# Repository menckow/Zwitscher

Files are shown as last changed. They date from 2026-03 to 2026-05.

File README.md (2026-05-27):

# Zwitscher - Directory-Based Random MP3 Player 🎵
Image of the Zwitscherbox
A smart, directory-based MP3 player based on the **ESP32-S3 (YB-ESP32-S3-AMP)** controller.

### ✨ Key features at a glance
- **Directory-based playback** with an intro sound for each folder.
- **PIR sensor** starts random MP3 playback when motion is detected — and, in v2, also fans out a family-circle signal so other boxes in the same circle light up.
- **Hardware controls** for volume (potentiometer) and folder selection (button).
- **Friendship lamp function (v2 family schema):** Lights up when *another* device in the same family circle sends a signal — whether that's a lamp button-press or another box's motion sensor. Lamp-originated signals are rendered with every 3rd LED in the complementary color so you can visually distinguish the source.
- **Family Circles:** Configure one or more `Familienkreise` (comma-separated) per box. The box belongs to all of them simultaneously and fans signals out to each.
- **Two separate MQTT integrations** for smart home systems (e.g. Home Assistant) and the friendship lamp function.
- **Configurable LED effects** (brightness, fade duration).
- **NVS memory** for volume and last folder to retain state after standby.
- **Integrated web portal** for easy configuration in the event of connection issues (including visual colour selection for the LED and family-circle assignment).
- **Web Upload OTA:** Drop a `.bin` directly via the configuration page — audio stops, LED turns blue, firmware is written in chunks and the box reboots automatically.
- **Central Device Management:** Fully compatible with the **Lamp Manager Dashboard**. Devices are grouped by family. Supports real-time status, version reporting, and Last Will (LWT) for offline detection.

## 🌟 Detailed features

- **Directory-based playback:** MP3s are organised into folders on the SD card. A button allows you to switch between directories.
- **Intro sound:** When switching folders, an `intro.mp3` file from the new directory is played automatically (if available).
- **Motion detector (PIR):** Detects movement and then plays a random MP3 file from the current directory. It also triggers the sending of an MQTT signal to the friendship lamp.
- **Hardware controls:**
  - **Potentiometer** for smooth and seamless volume control.
  - **Button** with debounce to switch directories.
- **Standby mode & NVS:**
  - After 5 minutes of inactivity, the ESP32 automatically enters **standby mode**. Audio playback stops and the LED ring is switched off, but Wi-Fi and MQTT remain active (important for the friendship lamp’s passive receiver function).
  - Wakes up internally when the PIR sensor is triggered or when a button is pressed.
  - The current directory and volume are stored in **NVS (Non-Volatile Storage)** to ensure data integrity.
- **Quiet Time (Do Not Disturb):**
  - Configurable via the Web UI, you can select your **Timezone** (e.g. Europe/Berlin) and define a sleep window (e.g. `22:00` to `08:00`). 
  - Using an internal background **NTP time sync**, the device will strictly ignore any incoming external colour MQTT signals during this window, ensuring it doesn't accidentally wake you up at night with bright LEDs. Local motion detection (PIR audio) continues to function.
- **Friendly lamp (RGB LED ring) — v2 family schema:**
  - **Presence:** If another device in the same family circle sends a signal — either a friend's lamp button-press or another box's PIR — your own LED ring lights up in the sender's color. Triggering *your own* PIR sensor does not cause your own lamp to light up, only fans the signal out to the family.
  - **Source-aware rendering:** Every signal carries a `sender_type` field. When the source is a **lamp**, every 3rd LED on the ring lights up in the complementary color — a clear visual hint that it came from a friend pressing a button. When the source is another **box** (PIR), the full ring lights up solid in the sender's color.
  - **Lamps ignore box signals** by design — a box's motion sensor doesn't wake a friend's lamp, only other boxes in the same family circle.
  - The LEDs fade in and out with a gentle **fade effect**. The duration and brightness can be adjusted in `config.txt`.
  - **Boot Check Sequence:** When powering on, the LEDs intuitively visualise the health of the boot process by lighting up individual LEDs sequentially in green (or red for failure) to signal initialisation stages (1. Hardware, 2. Wi-Fi, 3. Internal MQTT, 4. External MQTT).
- **Smart Home / MQTT Integration:**
  - The MQTT functionality is split into two parts:
    - An integration for **status messages** sent to an internal broker (e.g. Home Assistant).
    - A separate integration for the **Friendship Lamp feature**, which can also use a public broker.
    - Both can be enabled independently of one another. The device remains completely offline when both are disabled.
  - Connects via WiFi and sends real-time status updates via MQTT (volume, playback status, errors, current IP) **only** to the internal broker.
- **Timeouts:** The maximum playback duration for a random session is limited to 5 minutes to prevent endless playback.
- **Web configuration portal:** If a valid Wi-Fi connection cannot be established, the device launches its own password-protected access point (`Zwitscherbox`, **Password: `12345678`**). All settings can be conveniently configured via a web interface using drop-down menus (including a Wi-Fi scanner), without having to manually edit the SD card. The colour of the LED Ring (your colour) can be set particularly intuitively using a visual HTML colour picker. You can optionally secure this UI with a permanent administrator password.
- **SD Card File Manager:** The web interface also includes a fully-fledged `/files` file manager endpoint! This enables you to directly navigate the SD card directory, create new folders, delete files, and upload new MP3s over Wi-Fi without having to physically remove the SD card from the ESP32. Large MP3 files are smoothly transferred using asynchronous, memory-safe data chunks along with a live progress bar.
## 🛠 Hardware requirements

- **Board:** YB-ESP32-S3-AMP (based on Arduino ESP32 core >= v3.1.1)
- **SD card module:** Integrated (SPI)
- **PIR sensor:** Connected to `Pin 18`
- **Push button:** Connected to `Pin 17` (internal pull-up configured)
- **Potentiometer:** Connected to `Pin 4`
- **RGB LED ring (NeoPixel):** Data line connected to `Pin 16`
- **I2S Audio:** Pins for I2S configuration (integrated into the audio library).

## 🗂 Folder structure on the SD card
The SD card should be formatted as follows:
```
/
├── config.txt                   # (Optional) Wi-Fi and MQTT configuration
├── BirdSounds/                  # Directory 1
│   ├── intro.mp3                # Intro for Directory 1 (‘You are now listening to birds’)
│   ├── blackbird.mp3
│   └── thrush.mp3
└── Waterfall/                   # Directory 2
    ├── intro.mp3
    ├── waterfall1.mp3
    └── waterfall2.mp3
```

## ⚙️ Configuration (`config.txt`)

To use MQTT and Wi-Fi, create a `config.txt` file in the root directory of the SD card. Here is an example with all the new options:

```ini
# --- 1. MQTT activation ---
# Set this value to 1 to enable status reporting to your internal
# MQTT broker (e.g. Home Assistant).
MQTT_INTEGRATION=1

# Set this value to 1 to enable the Friend Lamp function via MQTT
#. This can be the internal broker or a public broker.
FRIENDLAMP_MQTT_INTEGRATION=1

# Note: If both of the above values are set to 0, the device remains offline (no Wi-Fi).

# --- 2. Wi-Fi settings ---
# Required if any of the MQTT integrations are enabled.
WIFI_SSID=YourWi-FiName
WIFI_PASS=YourWi-FiPassword

# --- 3. Internal MQTT broker (for Home Assistant) ---
MQTT_SERVER=192.168.1.100
MQTT_PORT=1883
MQTT_USER=mqtt_user
MQTT_PASS=mqtt_password
MQTT_CLIENT_ID=ESP32_AudioPlayer
MQTT_BASE_TOPIC=audioplayer

# --- 5. Friendship Lamp (RGB LED ring) ---
# Turns the LED ring hardware on (1) or off (0).
FRIENDLAMP_ENABLE=1
# Fixed transmission colour for THIS box in hexadecimal format (visually selectable in the web portal)
FRIENDLAMP_COLOR=0000FF
# v2 family schema: comma-separated list of family circle IDs the box belongs to.
# The box will subscribe to `fl/family/<id>/signal` for each entry and fan its
# PIR-triggered signals out to all of them. Whitespace is trimmed and entries
# are lowercased automatically.
FAMILY_IDS=schmidt,lieblings

# Control for LED effects
LED_FADE_EFFECT=1
LED_FADE_DURATION=1000
LED_BRIGHTNESS=100

# --- External broker for the friendship lamp (optional) ---
# If these fields are left blank, the internal broker is used automatically.
FRIENDLAMP_MQTT_SERVER=broker.hivemq.com
FRIENDLAMP_MQTT_PORT=1883
FRIENDLAMP_MQTT_USER=
FRIENDLAMP_MQTT_PASS=

# TLS encryption (only relevant for the external Friendlamp broker)
# Set to 1 to encrypt the connection to the Friendlamp broker (usually port 8883).
# The internal Home Assistant broker remains unaffected and unencrypted.
FRIENDLAMP_MQTT_TLS_ENABLED=0

# If TLS is enabled, the root certificate (BEGIN_CERT...END_CERT) must be included in config.txt.
```
If the file is omitted or both `_INTEGRATION` flags are set to `0`, the player runs completely offline.

## 🔘 Folder Taster & IP Address Visualization

The folder-change push button (connected to `Pin 17` or mapped Key on Audio Kit) has dual functions:
* **Short Press (< 3 seconds)**: Stops the current playback, changes to the next directory on the SD card, and plays the directory's intro sound.
* **Long Press (>= 3 seconds)**: Triggers the visual readout of the **last octet of the local IP address** on the RGB LED ring.
  * **Visual Pattern (Blinking Mode)**:
    * The last number of the IP address (e.g. `174` in `192.168.178.174`) is read out digit by digit.
    * For each digit $D$ (0 to 9), the entire LED ring flashes white $D + 1$ times (500 ms ON / 500 ms OFF).
    * To separate hundreds, tens, and ones, the entire LED ring lights up **Red for 1 second** (followed by a 500 ms pause).
  * **Note**: Releasing the button after the IP display starts will **not** trigger a folder change.

## 🚀 Installation & Compilation

This project uses **PlatformIO**. 
1. Clone or download the repository.
2. Open the folder in VSCode / PlatformIO.
3. The dependencies (such as `ESP32-audioI2S` and `PubSubClient`) are automatically downloaded via `platformio.ini` during the first build.
4. Connect the board via USB and click **Upload and Monitor**.

## 📡 MQTT Topics (v2 Family Schema)

When the MQTT connection is active, the box uses two topic families:

**Home Assistant / internal status** (based on `MQTT_BASE_TOPIC`, e.g. `audioplayer`):
* `audioplayer/status`: Status messages (‘Online’, ‘Playing Intro’, ‘Entering Standby’, ‘Woke up from Standby’, etc.)
* `audioplayer/volume`: Current volume.
* `audioplayer/directory`: The path to the newly selected directory on the SD card.
* `audioplayer/playing`: The path of the MP3 file currently being played or ‘STOPPED’.
* `audioplayer/ip_address`: The current IP address on the Wi-Fi network.
* `audioplayer/error`: Error messages (e.g. file system errors, missing MP3s).

**v2 family schema** (shared between lamps and boxes; consumed by the Dashboard):

| Purpose | Topic | Retained |
|---|---|---|
| Family signal (publisher + subscriber) | `fl/family/<familyId>/signal` | no |
| Device status (JSON) | `fl/device/<deviceId>/status` | **yes** |
| OTA per single device | `fl/device/<deviceId>/update/trigger` | no |
| OTA per family (boxes only) | `fl/family/<familyId>/update/trigger/box` | no |
| Global emergency OTA (boxes only) | `fl/_global/update/trigger/box` | no |
| OTA progress backchannel | `fl/device/<deviceId>/update/status` | no |

### 📝 Device Status Payload (retained JSON)

```json
{
  "type": "box",
  "fw": "V7.0.0",
  "state": "online",
  "color": "#0000FF",
  "families": ["schmidt", "lieblings"]
}
```

### 📝 Signal Payload (v2 family signal)

```json
{
  "client_id": "Kueche-Schmidt",
  "sender_type": "box",
  "color": "#0000FF",
  "effect": "fade",
  "duration": 30000,
  "ts": 1716729600
}
```

Fields explained:
- **`client_id`** (string): Unique device name (defined in `MQTT_CLIENT_ID`). Used for the **self-filter** so the box never reacts to its own messages.
- **`sender_type`** (string): Either `"lamp"` (button-press from a Friendship Lamp) or `"box"` (PIR-trigger from another box). Receivers use this to choose the LED rendering mode — lamps as source → complementary-color mode, boxes as source → solid color. Lamps additionally ignore any signal with `sender_type:"box"` so a box's motion sensor never wakes a friend's lamp.
- **`color`** (string): HEX color code (e.g. `#00FF00`). The literal `RAINBOW` triggers the rainbow effect.
- **`effect`** (string): `"fade"`, `"blink"`, or `"rainbow"`.
- **`duration`** (integer, ms): How long the LEDs stay lit before switching off (default `30000`).
- **`ts`** (Unix timestamp, optional): NTP-validated; signals older than 60 s are dropped to prevent retained messages from re-triggering after reconnect.

### 🔄 OTA Updates

Three update channels are supported, all using the same JSON payload format:

```json
{
  "url": "http://your-server.com/firmware.bin",
  "version": "7.0.1",
  "md5": "b3e3e3b3e3e3b3e3e3b3e3e3b3e3e3b3",
  "target_type": "box"
}
```

| Channel | Topic | Use case |
|---|---|---|
| Per-device | `fl/device/<deviceId>/update/trigger` | Update one specific box from the Dashboard |
| Per-family | `fl/family/<familyId>/update/trigger/box` | Update all boxes in a single family circle |
| Global | `fl/_global/update/trigger/box` | Emergency push across all boxes |

The `target_type` field is an optional defense-in-depth check — devices verify it matches their own type (`"box"`) before applying the update.

**Key Security & UI Features:**
- **Strict MD5 Validation:** The firmware verifies the provided `md5` hash internally before activating the new code. If the 32-character hash is missing or mismatched, the box aborts the update.
- **Dynamic LED Progress Ring:** During download, the RGB ring is repainted blue with progressive coverage.
- **Live MQTT Status Broadcasting:** The box streams download percentage updates (`Updating (30%)`, etc.) back to `fl/device/<deviceId>/update/status` and updates its main status topic as JSON.
- **Audio is automatically stopped** when an OTA starts, to keep the I²S DMA and Flash writes from colliding.
- If the installation fails the NeoPixel ring flashes red and the previous firmware continues to run.

### 💾 Web Upload OTA

In addition to the MQTT-triggered channels, the configuration page exposes a **Firmware-Update** section. Pick a `.bin`, optionally paste an MD5 hash, and submit. The box validates, writes via chunked `Update.write()`, and reboots automatically. Useful for first-time provisioning or when MQTT is temporarily unavailable.

## 📄 Licence

This project was developed exclusively as a private/open-source solution. 

## 🐞 Troubleshooting

### Build error: ‘not able to power down in light sleep’

When compiling the project, the following error message may appear, which typically occurs during the initialisation of the NeoPixel LED ring:

```
E (3637) rmt: rmt_new_tx_channel(269): unable to power down into light sleep
[  3664][E][esp32-hal-rmt.c:548] rmtInit(): GPIO 16 - RMT TX initialisation error.
```

- **Cause:** This error is caused by a bug in older versions of the ESP32 framework (Arduino Core) for PlatformIO. The RMT peripheral driver used by the NeoPixel library has a compatibility issue with the ESP32’s power-saving modes.

- **Solution:** To resolve this, the `platformio.ini` file has been modified. The `platform` setting has been set to a specific Git repository containing a newer version of the framework that fixes this error whilst also providing the necessary board definitions for the YB-ESP32-S3-AMP board.

The relevant line in `platformio.ini` is:
```ini
[env]
platform = https://github.com/pioarduino/platform-espressif32.git
```

This change ensures that the project is built using a compatible and bug-fixed version of the ESP32 framework.

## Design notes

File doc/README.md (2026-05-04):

# 🐦 Zwitscherbox & Friendship Lamp

A smart, motion-controlled MP3 player with an integrated light ring, Wi-Fi configuration portal, and smart home connectivity (MQTT).

## 🌟 Overview

This device combines an interactive MP3 player with a "Friendship Lamp". As soon as the motion detector (PIR) senses a person, the device plays a random audio file from the SD card.
Simultaneously, it can send a signal over the internet (MQTT) to a second box, causing its integrated LED ring to light up – so you instantly know when someone is thinking of you!

## ✨ Key Features

- **Motion Detection:** Automatically starts random audio playback upon detecting movement.
- **Directory System:** Supports multiple folders with different sounds. A button press changes the directory (confirmed by a short identification sound `intro.mp3`).
- **Friendship Lamp (LED Ring):**
  - **Standard Signal:** The entire ring illuminates (with a smooth fade if activated) and dims out again after 30 seconds.
  - **Friendship Signal:** The ring lights up, but every 3rd LED appears as a highlight in the *complementary color* for visual distinction.
- **Easy Setup:** No programming required – Wi-Fi, light color, and Smart Home server can be easily configured via a convenient web interface on your phone.
- **Smart-Home Ready:** Can be fully integrated into a Smart Home (e.g., Home Assistant) via MQTT (Status, Volume, Currently Playing Track, IP Address).
- **Auto Standby/Memory:** The device automatically remembers the current folder and volume. After 5 minutes of inactivity, the device independently enters power-saving mode.

---

## 🛠️ 1. Initial Setup (Wi-Fi Portal)

When the box is started for the first time (or cannot find its saved Wi-Fi), it automatically opens its own setup network.

1. Search for the Wi-Fi network **"Zwitscherbox"** with your smartphone or laptop and connect.
2. A login window (Captive Portal) should open automatically. Alternatively, open your browser and enter any address.
3. On the configuration page, you can configure all settings:
   - **Network Name & Password:** Enter your standard home Wi-Fi here.
   - **Select Color:** Determine which color your LED ring should light up in when the box receives a signal.
   - **MQTT / Smart Home:** (Optional) Enable the connection to your own or an external Smart Home server to connect the box with your friends.
4. Click on **"Save Configuration"**. The box will now restart and connect to the normal home Wi-Fi.

---

## 🎛️ 2. Operation on the Device

* **Volume Knob (Potentiometer):** Turn the knob to continuously adjust the volume.
* **Press Button:** Switches to the next audio folder on the SD card. A short identification melody is played during the switch, after which the system is immediately ready to react to motion again.
* **Motion Sensor:** If movement is detected, the device randomly selects an MP3 file from the current folder and plays it.

---

## 📁 3. SD Card Preparation

For the box to play music, the included SD card must be prepared as follows:

1. Create one or more subfolders on the SD card (e.g., `Birdsongs`, `ForestSounds`, `Music`).
2. Copy your desired sound files into each folder (they must end exactly with `.mp3`).
3. **IMPORTANT:** Add another MP3 file to every main folder and name it exactly `intro.mp3`. This will always be played briefly when someone switches to the folder using the button. This way, you immediately know which folder is currently activated.

---

## 💡 4. How Does the Illumination Work?

As soon as your box detects motion, it not only plays an audio file but also secretly broadcasts a signal in the background over the internet (MQTT) indicating which color you want to light up in.

* **Your box receives a generic "Zwitscherbox Signal":** The LED ring fills completely with the receiver color and smoothly transitions into a fade-out (dimming) after about 30 seconds. (Ideal for the main system).
* **Your box receives a signal on the "Friendship Channel":** A special pattern is visually displayed: The ring lights up, but every third LED shines as a highlight in the *complementary color*. This way, you can see at a glance on which of the two channels the box was currently addressed!

---

## 🔧 Technical Specifications (For the tech-savvy)
- **Components:** ESP32 (Model: YB-ESP32-S3-AMP), PIR Motion Sensor (Pin 18), Button (Pin 17), Analog Potentiometer (Pin 4), NeoPixel LED Ring (16 LEDs on Pin 16).
- **Storage:** NVS (Non-Volatile Storage) securely saves volume and folder selection across reboots.
- **Playback Safety:** Individual audio tracks have a built-in time limit of 5 minutes. If the room remains unused, the system silently enters standby mode.

---

## 📚 Additional Documentation

- [**PIR Ruhezeit & Sensor-Steuerung**](PIR_Ruhezeit_Dokumentation.md): Detailed information on PIR sensor behavior during Quiet Time and recent fixes.
- [**Architecture Refactoring**](Architecture_Refactoring.md): Overview of the V6 code structure and module separation.
- [**Wiring Diagram**](wiring_diagram.md): Connection guide for all hardware components.
- [**Visual Guide**](Zwitscherbox_Visual_Guide.md): Aesthetics and design overview.

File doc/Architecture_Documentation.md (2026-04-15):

# Zwitscherbox Software Architecture

Dieses Dokument beschreibt die objektorientierte (OOP) Architektur der Zwitscherbox (Friendship Lamp) Software. Die Code-Basis wurde entwickelt, um asynchrone Hardware-Ein-/Ausgaben, Webdienste, Dual-MQTT-Kommunikation und MP3-Wiedergabe stabil miteinander zu orchestrieren.

---

## 1. Klassendiagramm & Abhängigkeiten

Das Projekt nutzt das Prinzip der **Dependency Injection**. Das bedeutet, die `main.cpp` agiert lediglich als "Dirigent" (Orchestrator). Sie erstellt die Instanzen der einzelnen Manager-Klassen und ruft kontinuierlich deren `update()` Methoden in der `loop()` Schleife auf.

```mermaid
classDiagram
    class main {
        <<Orchestrator>>
        +setup()
        +loop()
    }
    
    class AppConfig {
        +load()
        +saveFromWeb()
        ~wifi_ssid
        ~friendlamp_enabled
    }

    class WebManager {
        -AsyncWebServer server
        -DNSServer dns
        +WebManager(port)
        +processDns()
        -setupWebServer()
        -startConfigPortal()
    }

    class MqttHandler {
        -PubSubClient mqttClient
        -PubSubClient mqttClientLamp
        +update()
        +publish()
        +publishLamp()
        -internalMqttReconnect()
    }

    class AudioEngine {
        -Audio audio
        -PlaybackState currentState
        -Preferences preferences
        +init()
        +update()
        -checkPirAndTimeout()
        -checkButton()
        -checkVolumePot()
    }

    class LedController {
        -Adafruit_NeoPixel strip
        -SemaphoreHandle_t mutex
        -ILedEffect* currentEffect
        +begin()
        +update()
        +setEffect(ILedEffect*)
    }

    class ILedEffect {
        <<Interface>>
        +update(strip) bool
    }

    %% Relationships
    main *-- AppConfig : instantiates globally
    main *-- WebManager : tick
    main *-- MqttHandler : tick
    main *-- AudioEngine : tick
    main *-- LedController : tick
    
    WebManager --> AppConfig : modifies
    MqttHandler --> AppConfig : reads
    AudioEngine --> AppConfig : reads
    
    AudioEngine --> MqttHandler : publishes status
    AudioEngine --> LedController : controls standby
    MqttHandler --> LedController : triggers colors
    LedController *-- ILedEffect : Strategy Pattern
    ILedEffect <|-- FadeEffect
    ILedEffect <|-- RainbowEffect
    ILedEffect <|-- BlinkEffect
```

---

## 2. Erklärung der Architektur (Klassen)

### 2.1 `AppConfig` (Datenhaltung)
Dies ist das Gehirn für Einstellungen. Es existiert global (`extern AppConfig config;`). 
- **Aufgabe**: Liest beim Start die Datei `/config.txt` von der SD-Karte ein und parst diese.
- Sämtliche anderen Klassen (`MqttHandler`, `WebManager`, etc.) greifen auf diese Instanz zu, um zu prüfen, ob z.B. `config.friendlamp_enabled` aktiv ist.

### 2.2 `WebManager` (Konfigurations-Portal)
Kapselt den Asynchronen Webserver (`AsyncWebServer`) und das Captive Portal (`DNSServer`).
- **Aufgabe**: Wenn keine WLAN-Verbindung möglich ist (oder über den Setup-Taster erzwungen), öffnet er ein eigens WLAN "Zwitscherbox".
- Bietet HTML-Seiten zur einfachen WLAN-, MQTT- und Farb-Konfiguration an.
- Nutzt asynchrone "Lambda-Funktionen", weshalb blockierender Code im `loop()` nicht mehr nötig ist.

### 2.3 `MqttHandler` (Netzwerk & Kommunikation)
Verwaltet simultan **zwei** MQTT-Broker:
1. Lokaler Home Assistant Broker (Steuerung / Status)
2. Externer/Öffentlicher Friendship Lamp Broker (Kommunikation mit anderen Lampen)
- **Aufgabe**: Sorgt asynchron dafür (`mqttHandler.update()`), dass die Verbindung gehalten wird. 
- Bei Empfang einer bestimmten Lampen-Nachricht übersetzt er diese in ein visuelles Signal und leitet es direkt an den `LedController` weiter.

### 2.4 `LedController` (Visuelle Effekte)
Abstraktionsschicht für den NeoPixel LED-Ring, die extrem weiche, blockierungsfreie Fades und Regenbögen ermöglicht.
- **Strategie-Muster (Strategy Pattern)**: Nutzt Effekte, die von der Basis `ILedEffect` erben. Der Controller ruft nur stumm `update()` auf. Ist der Effekt zu Ende (z.B. Fade Out), zerstört der LEDController das Effekt-Objekt automatisch aus dem Arbeitsspeicher.
- **Thread-Safety (FreeRTOS)**: Damit die asynchrone Audio-Bibliothek (`ESP32-audioI2S`) und der Webserver nicht gleichzeitig in den Speicher LEDs schreiben, wird ein "Mutex" (Semaphore) verwendet. Das verhindert Systemabstürze.

### 2.5 `AudioEngine` (State Machine & Hardware)
Die technisch komplexeste Klasse. Sie abstrahiert alle physischen Taster, den PIR Bewegungsmelder, das Poti und den I2S Verstärker. Da MP3-Dateien stoppen, starten und pausieren können, nutzt die Engine eine strikte **Zustandsmaschine (State Machine)**.

```mermaid
stateDiagram-v2
    [*] --> INITIALIZING
    INITIALIZING --> IDLE : init() / Intro Played
    
    IDLE --> PLAYING_RANDOM : PIR Triggered
    PLAYING_RANDOM --> IDLE : EOF (Song Finished)
    PLAYING_RANDOM --> IDLE : Button Press
    PLAYING_RANDOM --> IDLE : 5 Min Timeout
    
    IDLE --> STANDBY : 90 Min Inactivity
    STANDBY --> IDLE : PIR / Button Wakeup
```

- **Features**: Merkt sich per ESP32-eigenem NVS (Non-Volatile Storage via `Preferences`), in welchem Ordner (`dirIndex`) und auf welcher Lautstärke (`volume`) der Nutzer vor einem Neustart oder Stromausfall war.
- Verhindert Mehrfachtriggering (Entprellung / Debounce).
- Kommuniziert beim Wechsel in einen neuen State sofort per MQTT den Live-Status (z.B. `"Playing Audio"`, `"PIR Triggered"`).

> [!TIP]
> **Für Erweiterungen:** Wenn du z.B. einen neuen Taster einbauen willst, musst du nur den PIN definieren und eine entsprechende `checkNewButton()` in der `AudioEngine.cpp` hinzufügen. Die anderen Komponenten bleiben davon völlig unberührt!

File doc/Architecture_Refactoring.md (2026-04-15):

# Architecture Refactoring & Clean Code Guide

This document explains the comprehensive architectural refactoring implemented in the Zwitscherbox (Friendship Lamp) project. The goal of this refactoring was to convert a monolithic, hard-to-maintain `main.cpp` into a highly cohesive, modular, and maintainable C++ codebase.

## 1. The Monolithic Problem
Initially, all device logic was bundled inside `main.cpp`. This single file handled:
- WiFi and Networking (Access Point, Web Server, Captive Portal)
- MQTT dual-broker messaging (Home Assistant + Friendship Lamp external)
- Over-the-Air (OTA) firmware updates
- Hardware interaction (PIR sensor, button debouncing, potentiometer smoothing)
- SD Card file exploration and INI configuration parsing
- Adafruit NeoPixel animations via FreeRTOS mechanics
- Audio (`ESP32-audioI2S`) playback state

As features grew — notably the Friendship Lamp MQTT integration, LED Ring implementation, and full Web Configuration GUI — the single-file approach became difficult to navigate, prone to variable shadowing, and led to race conditions in LED updates.

## 2. The Modular Solution
The logic was aggressively decoupled into strict domains of responsibility. We created dedicated `.h` (Headers) and `.cpp` (Implementations) files in the `include/` and `src/` directories.

### `include/GlobalConfig.h`
A core file introduced to prevent circular dependencies. It acts as the central registry for all `extern` variables and shared configuration states (like `wifi_ssid`, `friendlamp_enabled`, `led_count`, `apMode`, and shared global pointers like the `AsyncWebServer`).

### `src/Config.cpp`
Responsible purely for SD card configuration mapping.
- Reads `config.txt` line by line.
- Cleanses string inputs and sets the global state variables.

### `src/WebManager.cpp`
Encapsulates all HTTP and asynchronous web interactions.
- Bootstraps the `ESPAsyncWebServer` for configuration.
- Manages the visual File Manager GUI.
- Hosts the Captive Portal `DNSServer` when the ESP32 acts as an Access Point (e.g. initial setup when no WiFi is reachable).

### `src/MqttHandler.cpp`
A heavily isolated networking module dedicated to real-time communication.
- Handles standard WiFi connection routines (`setup_wifi`).
- Implements parallel connection loops for the internal broker (Home Assistant) and the external broker (Friendshiplamp Public Broker) using separate `PubSubClient` instances.
- Securely executes Over-The-Air (OTA) `HTTPUpdate` firmwares over TLS.
- Houses the complex logic governing when and how MQTT clients reconnect upon failures.

### `src/LedController.cpp`
A hardware abstraction layer for the Adafruit NeoPixel strip.
- Introduces `neoPixelMutex` via FreeRTOS core concepts. This ensures `loop()` based LED fades and external MQTT command calls do not simultaneously write to the NeoPixel `strip` buffer.
- Computes non-blocking `rainbow` and `fade` algorithms.
- Exposes visual boot indicators (`setBootStatusLeds` and `setApModeLed`).

### `src/AudioHardware.cpp`
Encapsulates localized physical interactions without dirtying the network logic.
- Smooths analogue noise using moving-average algorithms to read the onboard Volume Potentiometer (`checkVolumePot`).
- Debounces the tactile physical switch (`checkButton`).
- Maps MP3 directories and injects files into memory vectors (`findMp3Directories`).

### `src/main.cpp`
Reduced to a pure **Orchestrator**. 
It simply calls `setup()` to sequentially initialize the modules (`Config` -> `Web` -> `MQTT` -> `LEDs` -> `Audio`), and it ticks the main `loop()`, acting as the traffic controller managing power states (PIR sensor wake-up, Deep-Sleep/Standby timeout).

## 3. Improvements Achieved
- **Decoupled Business Logic**: Testing network interactions without touching LED logic is now feasible.
- **Race Condition Immunity**: Enforced FreeRTOS mutexes prevent audio buffer collisions with intensive Neopixel math functions.
- **Boot Sequence Transparency**: Clean architectural scopes allowed us to neatly inject early-boot Status LEDs directly into `main.cpp` (SD Init), `WebManager` (AP Mode triggering), and `MqttHandler` (MQTT Check logic).
- **Soft-Reboot Safety**: By clearly separating `setup()` workflows from module functions, lingering NeoPixel Buffer states resulting from OTA soft-reboots were isolated and reliably neutralized upon instantiation.

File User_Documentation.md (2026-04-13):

# 🐦 Zwitscher - User Documentation

Welcome to the guide for your new **Zwitscherbox**!
The Zwitscherbox is an intelligent, directory-based MP3 player. It plays relaxing sounds at the push of a button or through motion detection, and can simultaneously communicate over the internet with other boxes or Friendship Lamps.

---

## 🛠️ 1. Initial Setup

When you turn on the box for the first time, it searches for a known Wi-Fi network. If it doesn't find one, it creates its own setup Wi-Fi.

1. Open the Wi-Fi settings on your smartphone or computer.
2. Search for the network named **`Zwitscherbox`** and connect to it.
3. Enter the default password: **`12345678`**
4. Usually, a configuration window (Captive Portal) will open automatically. If not, open your web browser and go to the address **`http://192.168.4.1`**.
5. In the web interface, you can conveniently adjust all settings via the menus:
   * Select your **Home Wi-Fi** from the list and enter your password.
   * You can easily set the **Color of your Zwitscherbox** using a visual color picker.
   * If required, you can also provide MQTT server settings (for Smart Home).
6. Click Save. The box will restart and connect to your home network.

*Tip:* You don't need to remove the SD card for these settings; the web interface will adapt the `config.txt` for you!

---

## 💡 2. Everyday Operation

### 🎛️ Adjusting the Volume
Turn the **rotary knob (potentiometer)** to continuously adjust the volume of the sounds. The box remembers this volume for next time.

### 🎵 Changing Folders (Sounds)
Press the **button** on the box. The Zwitscherbox then switches to the next directory on the SD card (e.g., from "Birds" to "Waterfall").
If there is a file named `intro.mp3` in the new folder, it will be played briefly as confirmation (e.g., a voice saying "Waterfall").

### 🚶 Motion Sensor (PIR)
The box is equipped with an infrared motion sensor:
* As soon as it detects movement, it **randomly** selects an MP3 file from the currently selected folder and plays it.
* At the same time (if Wi-Fi is configured), it sends an invisible signal to other connected Friendship Lamps or Zwitscherboxes in your network.

### 💤 Standby Mode
If no movement has been detected for 5 minutes and no sound is playing, the box automatically enters a power-saving **Standby Mode**. The LEDs turn off, but it remains connected to the Wi-Fi in the background. As soon as you press the button or movement is detected, it wakes up immediately.

---

## 🎨 3. The Friendship Lamp Feature

Your Zwitscherbox has an integrated illuminated LED ring. This lights up when **other** Zwitscherboxes or Friendship Lamps in your network are activated!

* **How it works:** If a friend's motion sensor triggers, the LED ring on *your* box will light up in their predefined color.
* **Good to know:** If *your* own motion sensor triggers, your own LED ring will not light up. It only forwards the signal to the others.
* The ring uses smooth **fade effects**. Brightness and duration can be configured in the settings.

---

## 📁 4. Adding MP3s (File Manager)

You don't need to unscrew the box or take out the SD card to add new sounds!

1. Make sure you are in the same Wi-Fi network as the Zwitscherbox.
2. Open the file manager in your browser via the IP address of your Zwitscherbox by appending `/files` (e.g., `http://192.168.1.50/files`).
3. In this file manager, you can access the SD card directly:
   * Create **new folders** (categories).
   * Delete **old MP3s**.
   * Upload **new sounds** wirelessly via Wi-Fi. A progress bar will show you how long the upload will take.

*Structure tip:* Create a separate folder for each sound category. Optionally, you can place a file named `intro.mp3` in each folder, which will be played when you switch to this folder using the button.

---

## 📡 5. Smart Home Integration (For Professionals)

The Zwitscherbox can optionally be integrated into Smart Home systems (like Home Assistant):
* It has **two separate MQTT interfaces**: One for status messages to your internal Smart Home, and a separate one for the global Friendship Lamp connection.
* It transmits real-time values such as volume, playback status, the current IP address, and potential errors.
* It is fully compatible with the central **Lamp Manager Dashboard** for real-time monitoring of your device fleet.

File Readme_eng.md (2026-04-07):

# Zwitscher - Directory-Based Random MP3 Player 🎵
Image of the Zwitscherbox
A smart, directory-based MP3 player based on the **ESP32-S3 (YB-ESP32-S3-AMP)** controller.

### ✨ Key features at a glance
- **Directory-based playback** with an intro sound for each folder.
- **PIR sensor** starts random MP3 playback when motion is detected.
- **Hardware controls** for volume (potentiometer) and folder selection (button).
- **Friendship lamp function:** Lights up when *another* box detects motion.
- **Two separate MQTT integrations** for smart home systems (e.g. Home Assistant) and the friendship lamp function.
- **Configurable LED effects** (brightness, fade duration).
- **NVS memory** for volume and last folder to retain state after standby.
- **Integrated web portal** for easy configuration in the event of connection issues (including visual colour selection for the LED).

## 🌟 Detailed features

- **Directory-based playback:** MP3s are organised into folders on the SD card. A button allows you to switch between directories.
- **Intro sound:** When switching folders, an `intro.mp3` file from the new directory is played automatically (if available).
- **Motion detector (PIR):** Detects movement and then plays a random MP3 file from the current directory. It also triggers the sending of an MQTT signal to the friendship lamp.
- **Hardware controls:**
  - **Potentiometer** for smooth and seamless volume control.
  - **Button** with debounce to switch directories.
- **Standby mode & NVS:**
  - After 5 minutes of inactivity, the ESP32 automatically enters **standby mode**. Audio playback stops and the LED ring is switched off, but Wi-Fi and MQTT remain active (important for the friendship lamp’s passive receiver function).
 - Wakes up internally when the PIR sensor is triggered or when a button is pressed.
  - The current directory and volume are stored in **NVS (Non-Volatile Storage)** to ensure data integrity.
- **Friendly lamp (RGB LED ring):**
  - **CORRECTION:** If *another* box detects movement and sends an MQTT signal, your own LED ring lights up in the colour of the sender. Triggering *your own* PIR sensor **does not** cause your own lamp to light up, but only sends a signal to the others.
  - **Two Topics:** The box distinguishes between messages on the `ZWITSCHERBOX_TOPIC` (the ring lights up completely in the colour sent) and the `FRIENDLAMP_TOPIC` (every third LED on the ring lights up in the complementary colour).
  - The LEDs fade in and out with a gentle **fade effect**. The duration and brightness can be adjusted in `config.txt`.
- **Smart Home / MQTT Integration:**
  - The MQTT functionality is split into two parts:
    - An integration for **status messages** sent to an internal broker (e.g. Home Assistant).
    - A separate integration for the **Friendship Lamp feature**, which can also use a public broker.
    - Both can be enabled independently of one another. The device remains completely offline when both are disabled.
  - Connects via WiFi and sends real-time status updates via MQTT (volume, playback status, errors, current IP).
- **Timeouts:** The maximum playback duration for a random session is limited to 5 minutes to prevent endless playback.
- **Web configuration portal:** If a valid Wi-Fi connection cannot be established, the device launches its own password-protected access point (`Zwitscherbox`, **Password: `12345678`**). All settings can be conveniently configured via a web interface using drop-down menus (including a Wi-Fi scanner), without having to manually edit the SD card. The colour of the friendship lamp can be set particularly intuitively using a visual HTML colour picker.
## 🛠 Hardware requirements

- **Board:** YB-ESP32-S3-AMP (based on Arduino ESP32 core >= v3.1.1)
- **SD card module:** Integrated (SPI)
- **PIR sensor:** Connected to `Pin 18`
- **Push button:** Connected to `Pin 17` (internal pull-up configured)
- **Potentiometer:** Connected to `Pin 4`
- **RGB LED ring (NeoPixel):** Data line connected to `Pin 16`
- **I2S Audio:** Pins for I2S configuration (integrated into the audio library).

## 🗂 Folder structure on the SD card
The SD card should be formatted as follows:
```
/
├── config.txt                   # (Optional) Wi-Fi and MQTT configuration
├── BirdSounds/                # Directory 1
│   ├── intro.mp3                # Intro for Directory 1 (‘You are now listening to birds’)
│   ├── blackbird.mp3
│   └── thrush.mp3
└── Waterfall/                  # Directory 2
    ├── intro.mp3
    ├── waterfall1.mp3
    └── waterfall2.mp3
```

## ⚙️ Configuration (`config.txt`)

To use MQTT and Wi-Fi, create a `config.txt` file in the root directory of the SD card. Here is an example with all the new options:

```ini
# --- 1. MQTT activation ---
# Set this value to 1 to enable status reporting to your internal
# MQTT broker (e.g. Home Assistant).
MQTT_INTEGRATION=1

# Set this value to 1 to enable the Friend Lamp function via MQTT
#. This can be the internal broker or a public broker.
FRIENDLAMP_MQTT_INTEGRATION=1

# Note: If both of the above values are set to 0, the device remains offline (no Wi-Fi).

# --- 2. Wi-Fi settings ---
# Required if any of the MQTT integrations are enabled.
WIFI_SSID=YourWi-FiName
WIFI_PASS=YourWi-FiPassword

# --- 3. Internal MQTT broker (for Home Assistant) ---
MQTT_SERVER=192.168.1.100
MQTT_PORT=1883
MQTT_USER=mqtt_user
MQTT_PASS=mqtt_password
MQTT_CLIENT_ID=ESP32_AudioPlayer
MQTT_BASE_TOPIC=audioplayer
# --- 5. Friendship Lamp (RGB LED ring) ---
# Turns the LED ring hardware on (1) or off (0).
FRIENDLAMP_ENABLE=1
# Fixed transmission colour for THIS box in hexadecimal format (visually selectable in the web portal)
FRIENDLAMP_COLOR=0000FF
# Topic for friendship colour signals
FRIENDLAMP_TOPIC=friendship/colour
# Topic for Zwitscherbox colour signals
ZWITSCHERBOX_TOPIC=zwitscherbox/colour

# Control for LED effects
LED_FADE_EFFECT=1
LED_FADE_DURATION=1000
LED_BRIGHTNESS=100

# --- External broker for the friendship lamp (optional) ---
# If these fields are left blank, the internal broker is used automatically.
FRIENDLAMP_MQTT_SERVER=broker.hivemq.com
FRIENDLAMP_MQTT_PORT=1883
FRIENDLAMP_MQTT_USER=
FRIENDLAMP_MQTT_PASS=

# TLS encryption (only relevant for the external Friendlamp broker)
# Set to 1 to encrypt the connection to the Friendlamp broker (usually port 8883).
# The internal Home Assistant broker remains unaffected and unencrypted.
FRIENDLAMP_MQTT_TLS_ENABLED=0

# If TLS is enabled, the root certificate (BEGIN_CERT...END_CERT) must be included in config.txt.
```
If the file is omitted or both `_INTEGRATION` flags are set to `0`, the player runs completely offline.

## 🚀 Installation & Compilation

This project uses **PlatformIO**. 
1. Clone or download the repository.
2. Open the folder in VSCode / PlatformIO.
3. The dependencies (such as `ESP32-audioI2S` and `PubSubClient`) are automatically downloaded via `platformio.ini` during the first build.
4. Connect the board via USB and click **Upload and Monitor**.

## 📡 MQTT Topics

When the MQTT connection is active, the setup publishes to the following topics (based on `MQTT_BASE_TOPIC`, e.g. `audioplayer`):

* `audioplayer/status`: Status messages (‘Online’, ‘Playing Intro’, ‘Entering Standby’, ‘Woke up from Standby’, etc.)
* `audioplayer/volume`: Current volume.
* `audioplayer/directory`: The path to the newly selected directory on the SD card.
* `audioplayer/playing`: The path of the MP3 file currently being played or ‘STOPPED’.
* `audioplayer/ip_address`: The current IP address on the Wi-Fi network.
* `audioplayer/friendlamp`: Used to exchange colours for the friendship lamp between devices.
* `audioplayer/error`: Error messages (e.g. file system errors, missing MP3s).

### 📝 MQTT JSON Payload (Friendship Lamp & Twitter Box)

The hardware communicates with each other using a structured JSON format for colour transmission and effect control. For reasons of backwards compatibility, older string messages in the legacy format (`SenderID:HexColour`) are also decoded without error (fallback mechanism). 

A standard JSON packet from the sender (or your smart home system) looks like this:

```json
{
  ‘client_id’: ‘My_PIR_Sensor_ESP’,
  ‘color’: ‘FF0000’,
  ‘effect’: ‘fade’,
  ‘duration’: 30000
}
```

- **`client_id` (string):** The unique name of the device playing the content (used to ensure the box does not respond to its own messages and to prevent infinite loops).

- **`color` (string):** The HEX colour code (e.g. `00FF00` for green). If the word `RAINBOW` is passed as the colour, the hidden, circular light effect starts.
- **`effect` (string):** Controls the animation behaviour of the NeoPixel LEDs. Supported values are `‘fade’` (soft fade), `“blink”` (flashing once per second in time with the beat) and `‘rainbow’`.
- **`duration` (Integer):** Time in milliseconds for how long the LEDs should remain lit before switching off automatically (default: `30000` = 30 seconds). This allows Home Assistant to perfectly control the duration of the visual signals depending on the application scenario (e.g. short alarm vs. long background lighting).

## 📄 Licence

This project was developed exclusively as a private/open-source solution. 

## 🐞 Troubleshooting

### Build error: ‘not able to power down in light sleep’

When compiling the project, the following error message may appear, which typically occurs during the initialisation of the NeoPixel LED ring:

```
E (3637) rmt: rmt_new_tx_channel(269): unable to power down into light sleep
[  3664][E][esp32-hal-rmt.c:548] rmtInit(): GPIO 16 - RMT TX initialisation error.
```

- **Cause:** This error is caused by a bug in older versions of the ESP32 framework (Arduino Core) for PlatformIO. The RMT peripheral driver used by the NeoPixel library has a compatibility issue with the ESP32’s power-saving modes.

- **Solution:** To resolve this, the `platformio.ini` file has been modified. The `platform` setting has been set to a specific Git repository containing a newer version of the framework that fixes this error whilst also providing the necessary board definitions for the YB-ESP32-S3-AMP board.

The relevant line in `platformio.ini` is:
```ini
[env]
platform = https://github.com/pioarduino/platform-espressif32.git
```

This change ensures that the project is built using a compatible and bug-fixed version of the ESP32 framework.

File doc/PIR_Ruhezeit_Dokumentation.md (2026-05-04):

# Dokumentation: PIR Ruhezeit & Sensor-Steuerung

Diese Dokumentation beschreibt die Funktionalität und Konfiguration der PIR-Sensor-Steuerung während der Ruhezeit (Do Not Disturb) in der Zwitscherbox V6.

## Übersicht

Der PIR-Bewegungsmelder löst normalerweise bei jeder erkannten Bewegung die Wiedergabe eines zufälligen Audiostücks aus. Mit der Einführung der **PIR Ruhezeit-Option** kann dieses Verhalten nun zeitgesteuert eingeschränkt werden, um beispielsweise nächtliche Störungen zu vermeiden.

## Funktionen

### 1. PIR in Ruhezeit deaktivieren
Zusätzlich zur allgemeinen Ruhezeit (in der nur die LED-Signale unterdrückt werden) kann nun explizit festgelegt werden, ob auch der PIR-Sensor in diesem Zeitraum stumm bleiben soll.

*   **Option:** `PIR in Ruhezeit deaktivieren`
*   **Verhalten:** Wenn aktiv, ignoriert die Box jegliche Bewegungserkennung zwischen der eingestellten Start- und Endzeit.
*   **Voraussetzung:** Ein aktiver NTP-Server-Sync ist notwendig, damit die Box die aktuelle Uhrzeit kennt.

### 2. Konfiguration über das Webinterface
Die Einstellungen befinden sich im Web-Konfigurationsmenü unter dem Reiter **"Ruhezeit (Bitte nicht stören)"**:

*   **Ruhezeit aktivieren:** Schaltet die zeitgesteuerte Unterdrückung generell ein.
*   **PIR in Ruhezeit deaktivieren:** Setzt den PIR-Sensor während der Ruhezeit außer Kraft.
*   **Start/Ende:** Definiert das Zeitfenster (z.B. 22:00 bis 08:00).

## Technische Implementierung

### Konfigurations-Variablen (`AppConfig.h/cpp`)
Die Einstellung wird in der `config` gespeichert:
```cpp
bool quiet_time_pir_disabled; // Speichert den Status der Checkbox
```

### Logik-Prüfung (`AudioEngine.cpp`)
In der Methode `checkPirAndTimeout()` wird vor dem Auslösen der Wiedergabe geprüft, ob der Sensor ignoriert werden soll:

```cpp
if (pirStateHigh) {
    // Prüfung ob PIR während der Ruhezeit ignoriert werden soll
    if (config.quiet_time_pir_disabled && mqttHandler.isQuietTime()) {
        // Bewegung erkannt, aber ignoriert
        return;
    }
    // ... normaler Trigger-Code
}
```

### Zeitprüfung (`MqttHandler.cpp`)
Die Methode `isQuietTime()` berechnet basierend auf der aktuellen Systemzeit und der konfigurierten Zeitzone, ob das aktuelle Zeitfenster innerhalb der Ruhezeit liegt.

## Letzte Fehlerbehebungen (PIR)

*   **Pin-Korrektur:** Der PIR-Sensor wurde von Pin 16 auf den korrekten Hardware-Pin **18** verschoben.
*   **API-Anpassung:** Aufgrund von Breaking Changes in der `ESP32-audioI2S` Bibliothek (v3.0+) wurde der Trigger-Mechanismus auf das neue Callback-System (`Audio::audio_info_callback`) umgestellt, um zuverlässiges Auslösen nach dem Ende eines Tracks zu gewährleisten.

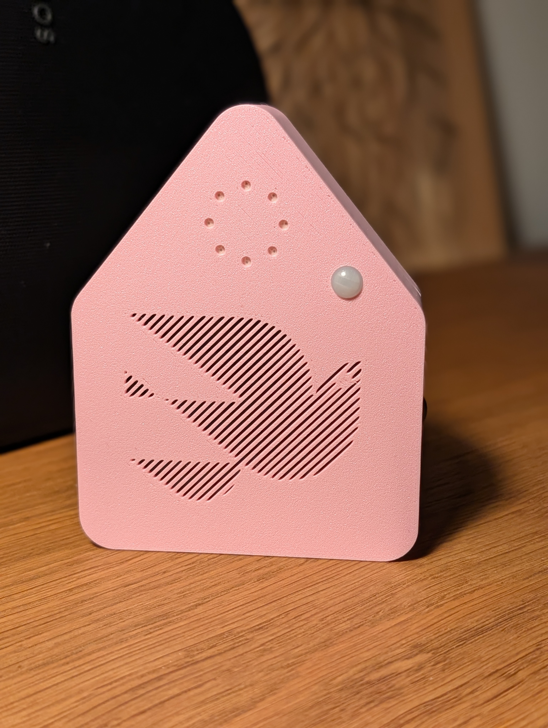
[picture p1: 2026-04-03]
case/PXL_20260402_210148150.PORTRAIT.jpg

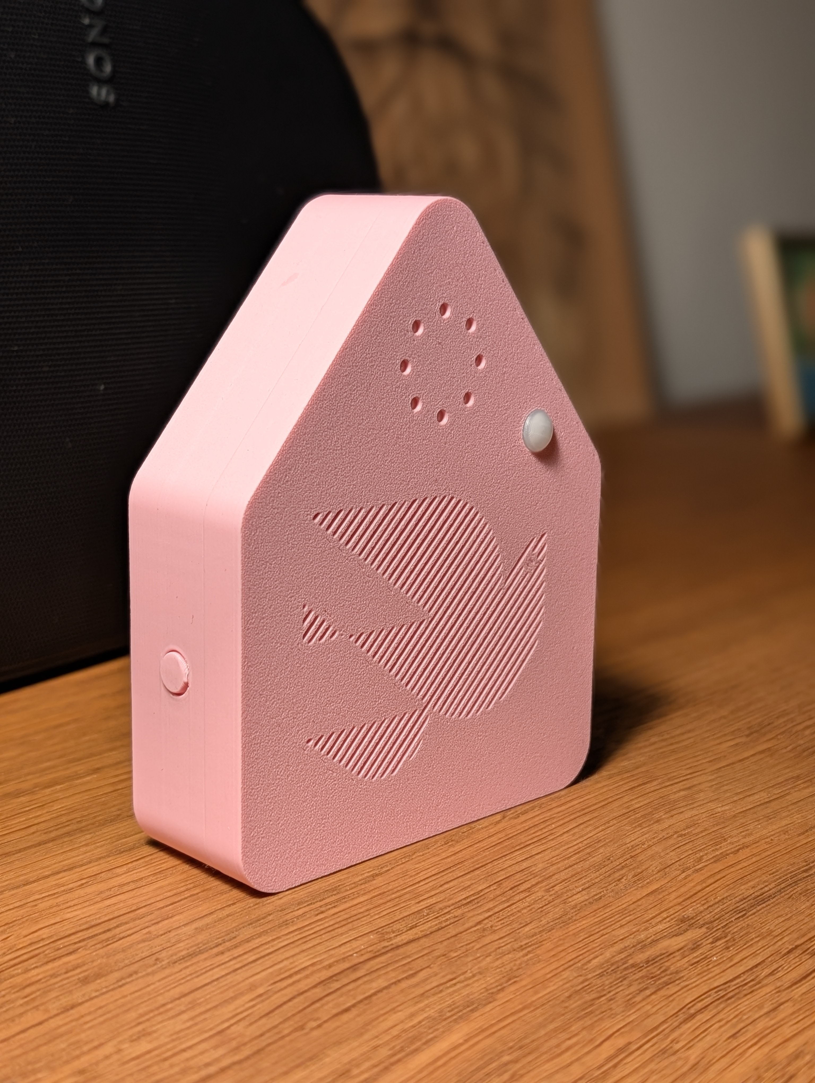
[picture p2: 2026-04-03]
case/PXL_20260402_210212310.PORTRAIT.jpg

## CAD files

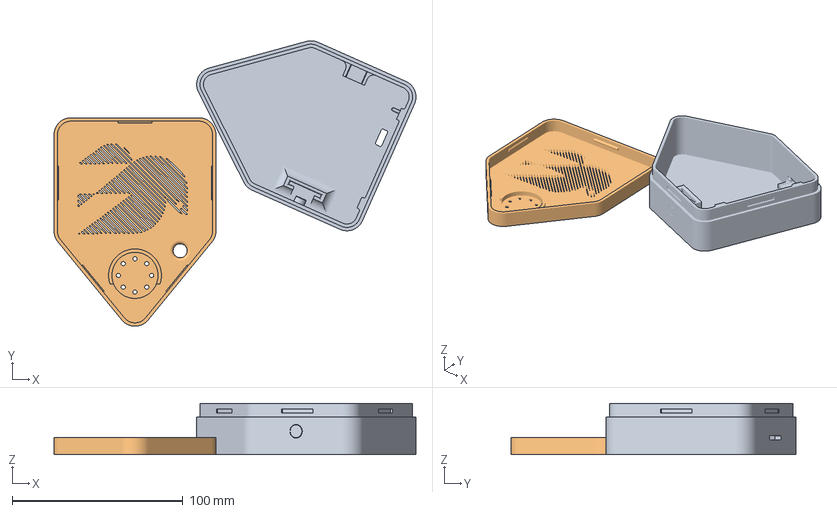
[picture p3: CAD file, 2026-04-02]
case/ZwitscherboxV5.3mf
212.3 x 167.4 x 30.0 mm
ZwitscherKleinschmal_Boden.step
ZwitscherKleinschmal_Deckel.step

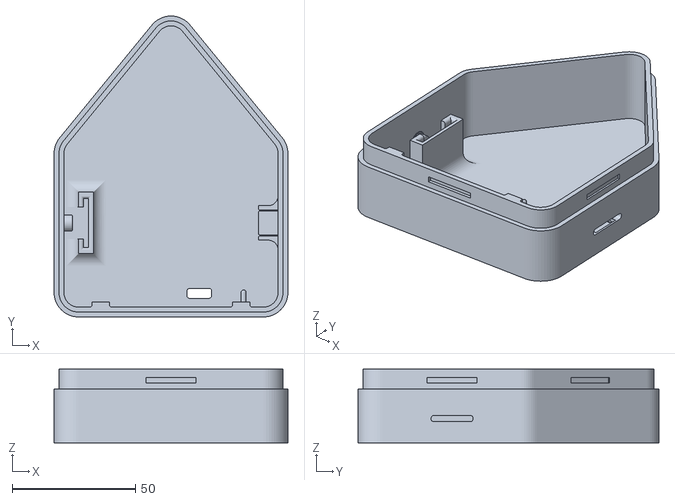
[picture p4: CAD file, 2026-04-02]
case/ZwitscherKleinschmal_Boden.stl
95.0 x 122.3 x 30.0

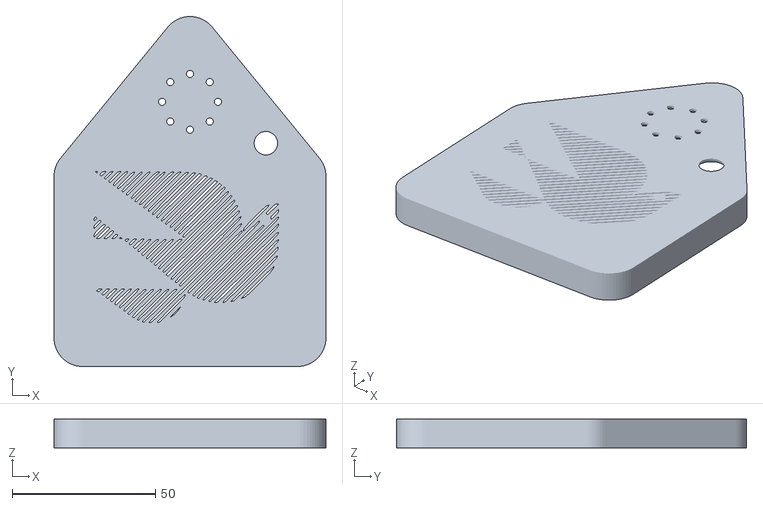
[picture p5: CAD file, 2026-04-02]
case/ZwitscherKleinschmal_Deckel.stl
95.0 x 122.3 x 10.0

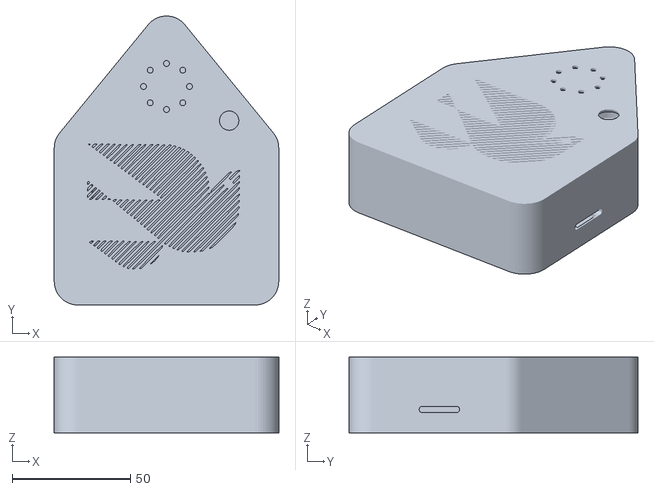
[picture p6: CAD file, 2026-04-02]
case/ZwitscherKleinschmal.stl
95.0 x 122.3 x 32.0

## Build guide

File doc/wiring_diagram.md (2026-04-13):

# Wiring Diagram Zwitscherbox (with Friendship Lamp)

This document describes the hardware wiring of the essential external components to the ESP32 (YB-ESP32-S3-AMP) for the "Zwitscherbox" project.

## 1. Complete Project Wiring

The following diagram shows the overall setup including the PIR sensor, button, potentiometer, and the NeoPixel LED ring.

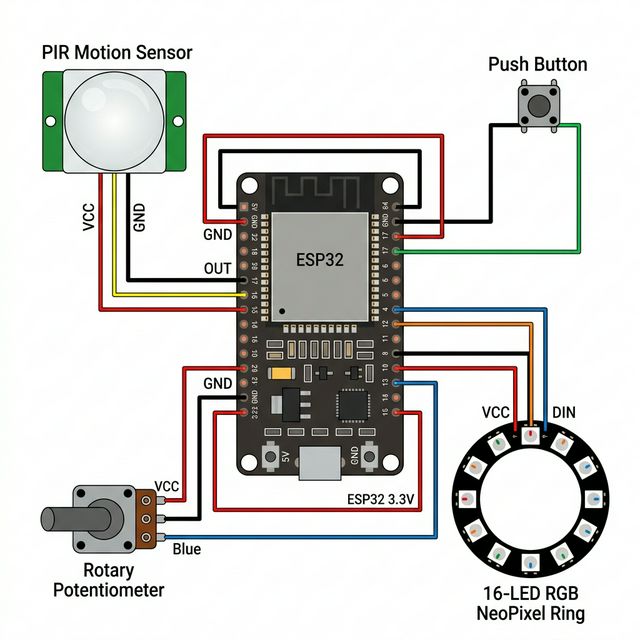
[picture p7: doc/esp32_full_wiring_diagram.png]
Complete Wiring Schema


### Pin Assignments Overview:

**PIR Motion Sensor:**
- **VCC:** 5V 
- **GND:** GND
- **OUT / Signal:** Pin 18

**Rotary Potentiometer (Volume):**
- **VCC (Outer Pin 1):** 3.3V (Important: do not use 5V, as the ADC measures a maximum of 3.3V)
- **GND (Outer Pin 2):** GND
- **OUT / Wiper (Middle Pin):** Pin 4

**Push Button (Directory Change):**
- **First Contact:** GND
- **Second Contact:** Pin 17 *(The resistor is switched via the internal pull-up in the ESP32)*

---

## 2. Detailed Wiring: Friendship Lamp (LED Ring)

The "Friendship Lamp" consists of a 16-LED NeoPixel RGB ring (WS2812B).
Please note that the data line (DIN) must be connected to Pin 12.

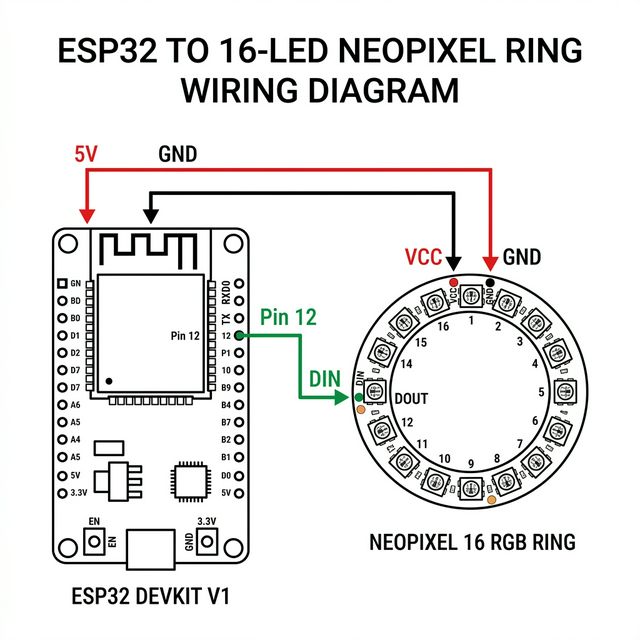
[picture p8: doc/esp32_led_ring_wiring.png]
NeoPixel Wiring Schema


### Connection Details LED Ring:
- **Black (GND):** To a GND pin on the ESP32.
- **Red (5V/VCC):** To the 5V pin (often `VBUS` or `VIN`) on the ESP32.
- **Green (DIN):** To Pin 12 on the ESP32.

*(Important: Use the pad on the LED ring labeled `DIN` or `Data In`, not `DOUT`!)*

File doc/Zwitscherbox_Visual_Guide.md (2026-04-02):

# 📖 Detailed Guide: The Zwitscherbox

> [!NOTE]
> Welcome to the **Zwitscherbox**! This interactive and connected music box plays soothing sounds when you enter the room – and lights up in a special color thanks to the "Friendship Lamp" feature when your friends walk past their box. Here is everything you need to know.

---

## 🛠️ Part 1: Preparation and SD Card Setup

Before you can start using the Zwitscherbox, the included or your own MicroSD card needs to be prepared. This ensures that the box can find your audio content and connect to the internet (WiFi & MQTT).

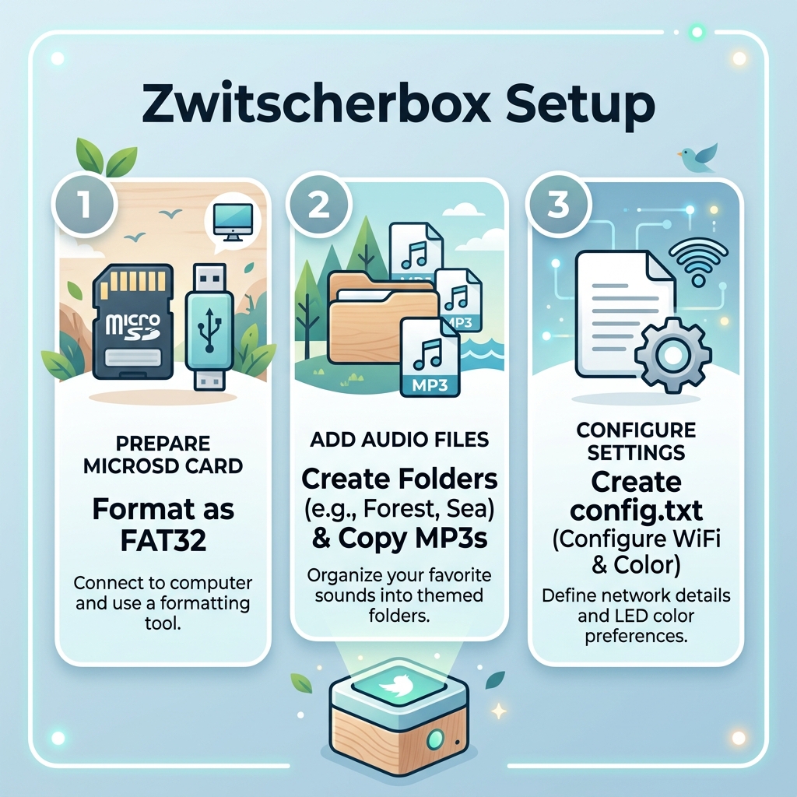
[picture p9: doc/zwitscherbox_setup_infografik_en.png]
Zwitscherbox Setup Infographic


### 1. FAT32 Formatting
The SD card **must** be formatted in `FAT32`. You can use the Disk Utility on your Mac or a corresponding tool on a PC for this.

### 2. Folder Structure and MP3s
You can create different "themes" for your sounds. 
* Create folders in the root directory like `Forest`, `Sea` or `Meditation`.
* Copy your MP3 files into these folders.
* *Tip:* If you want, you can place a file named `intro.mp3` in every folder. This track is always played precisely when you manually switch to that folder (see Part 2).

### 3. Configuration (`config.txt`)
The box needs your login credentials for its internet features (WiFi & MQTT for the Friendship Lamp). Create a file with the exact name `config.txt` in the root directory of the SD card:
* **WLAN_SSID**: Your WiFi name (Example: `WLAN_SSID=MyWiFi`).
* **WLAN_PASS**: Your WiFi password.
* **FRIENDLAMP_COLOR**: The color of your box in HEX format (e.g. `FF0000` for red). Your friends' boxes will light up in this color whenever you walk past your box!

---

## 🎶 Part 2: Quick Start & Daily Usage

Once the SD card is inserted and you supply the box with power, it will initialize and be ready to use. Daily usage is very simple!

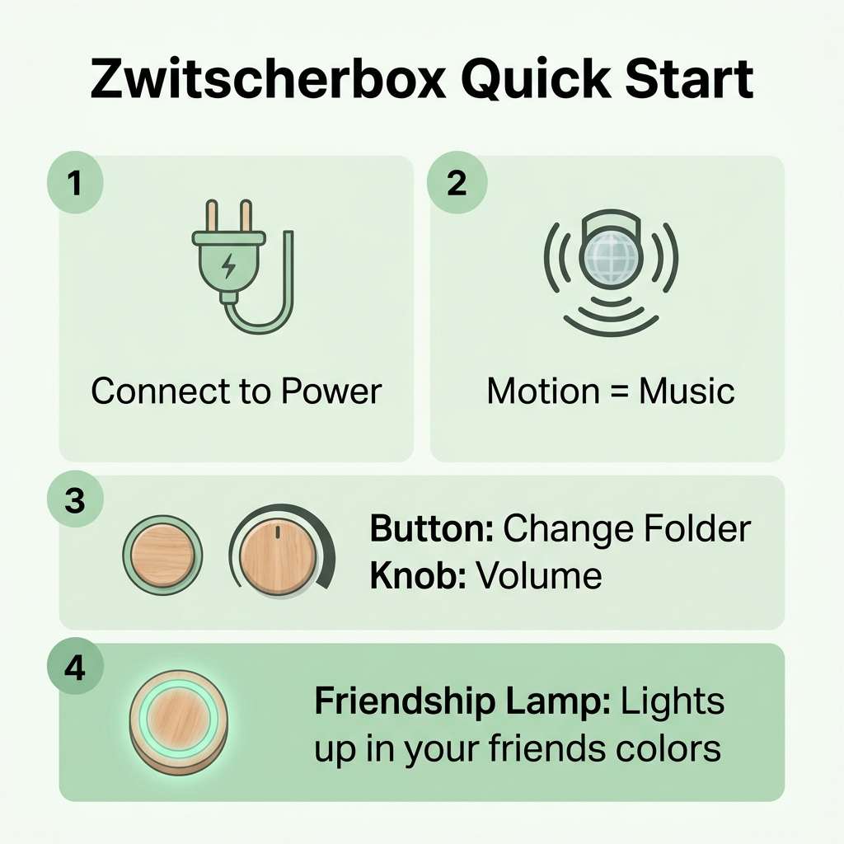
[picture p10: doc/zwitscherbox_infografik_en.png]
Zwitscherbox Quick Start Infographic


### 1. Power Supply
Simply plug the box into an outlet or connect it to a power bank. Once it has booted up, it monitors the room.

### 2. Automatic Playback (Motion = Music)
The special feature of the Zwitscherbox: You don't have to actively turn it on. The built-in motion sensor (PIR sensor) detects when someone is in the room and starts the music. After 5 minutes of inactivity, it discreetly goes into standby mode to save power, and only wakes up upon detecting new motion.

### 3. Folder Selection & Volume
* **Button**: A short press on the button switches to the next sound folder on the SD card (e.g. moving from "Forest" to "Sea"). If available, the `intro.mp3` is played as confirmation.
* **Volume Knob**: You can easily and seamlessly adjust the volume using the rotary knob (potentiometer).

### 4. The Friendship Lamp
The LED ring on the box is more than just decoration: It connects you with your loved ones.
* **Action**: When *you* trigger motion in front of your box, it sends an invisible signal to your friends' boxes. Thus, they know you're doing well.
* **Reaction**: Conversely, *your* LED ring magically lights up in an assigned color as soon as one of your friends triggers their box. This is meant to spread small smiles, no matter where you are.

> [!TIP]
> **Any questions?** If an error occurs (e.g. wrong WiFi password), the LED ring typically blinks in a specific pattern to indicate problems during initialization.

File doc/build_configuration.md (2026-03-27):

# Anpassung der Build-Konfiguration

Dieses Dokument erklärt die notwendige Anpassung in der `platformio.ini`-Datei, um ein bekanntes Kompatibilitätsproblem mit dem ESP32 zu beheben.

## Das Problem

Bei der Kompilierung des Projekts trat ein Fehler auf, der sich auf den RMT-Treiber des ESP32 bezieht, welcher für die Ansteuerung von NeoPixel-LEDs (dem LED-Ring) verwendet wird. Die Fehlermeldung lautete:

```
E (3637) rmt: rmt_new_tx_channel(269): not able to power down in light sleep
```

Dieser Fehler tritt auf, weil eine ältere Version des ESP32-Frameworks (Arduino Core) ein Problem mit dem Energiemanagement des RMT-Treibers hat.

## Die Lösung

Um das Problem zu beheben, muss PlatformIO angewiesen werden, eine neuere, fehlerbereinigte Version des ESP32-Frameworks zu verwenden. Gleichzeitig muss sichergestellt werden, dass diese Version die spezifischen Definitionen für das YB-ESP32-S3-AMP-Board kennt.

Die Lösung besteht darin, die `platform`-Einstellung in der `platformio.ini` auf ein spezifisches Git-Repository zu setzen, das eine funktionierende Kombination aus Framework und Board-Definitionen bereitstellt.

Die korrekte Zeile in `platformio.ini` lautet:
```ini
[env]
platform = https://github.com/pioarduino/platform-espressif32.git
```

Diese Einstellung zwingt PlatformIO, die Plattform von diesem Repository zu klonen, was das Build-Problem behebt und eine erfolgreiche Kompilierung ermöglicht.

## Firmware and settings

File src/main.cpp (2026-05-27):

/*
  Directory-Based Random MP3 Player with Intro, PIR, Volume, Timeout, Button
  Version E: Added NVS save/load for directory index and volume across Deep Sleep.
  based on a YB-ESP32-S3-AMP https://github.com/yellobyte/ESP32-DevBoards-Getting-Started/tree/main/boards/YB-ESP32-S3-AMP
  Letzte Änderung: NVS Implementierung
*/

#include "Audio.h"
#include <Arduino.h>
#include <FS.h>
#include <SD.h>
#include <SPI.h>
#include <vector>
#include "esp_sleep.h"
#include <Preferences.h> 
#include <PubSubClient.h>
#include <WiFi.h>
#include <WiFiClientSecure.h>
#include <Adafruit_NeoPixel.h>
#include <ArduinoJson.h>
#include <HTTPClient.h>
#include <HTTPUpdate.h>

const char* FW_VERSION = "7.2.1"; // Major.Minor.Patch, wird in OTA-Updates und im Webinterface angezeigt
#include <ESPAsyncWebServer.h> // For Webserver
#include <AsyncTCP.h>          // For Webserver
#include <DNSServer.h>         // For Captive Portal
#include "freertos/semphr.h"
#include "MqttHandler.h"
#include "LedController.h"
#include "WebManager.h"
#include "GlobalConfig.h"
#include "HardwareConfig.h"
// --- Pin-Definitionen ---
// Pins are now centralized in include/HardwareConfig.h
// config.led_count wird in der AppConfig verwaltet

Adafruit_NeoPixel strip(DEFAULT_LED_COUNT, LED_PIN, NEO_GRB + NEO_KHZ800);
LedController ledCtrl(strip);

// --- Timeout-Konstanten ---
const unsigned long maxPlaybackDuration = 5 * 60 * 1000UL;
const unsigned long deepSleepInactivityTimeout = 5 * 60 * 1000UL;

// --- Globale Objekte und Variablen ---
SPIClass *spi_onboardSD = new SPIClass(FSPI);
Audio audio;

// Instantiate Application Configuration
AppConfig config;

#include "AudioEngine.h"

AudioEngine audioEngine(audio);

// --- Lautstärke prüfen --- 

// --- Taster prüfen --- 
// --- Setup --- 
void setup() {
    ledCtrl.begin();
    pinMode(LED_BUILTIN, OUTPUT); digitalWrite(LED_BUILTIN, LOW);
    pinMode(POT_PIN, INPUT);
    pinMode(PIR_PIN, INPUT);
    pinMode(BUTTON_PIN, INPUT_PULLUP);

    Serial.begin(115200); Serial.println("\nStarting: Directory MP3 Player V_F (MQTT)...");

    strip.updateLength(64); // Kurzzeitig auf 64 LEDs erweitern, um alle alten Zustände eines Soft-Reboots (OTA/Lokal) zu killen!
    strip.begin(); 
    strip.clear();
    strip.show();
    
    strip.updateLength(DEFAULT_LED_COUNT); // Für den weißen Startblitz auf Standard zurück
    strip.setBrightness(100); // Heller kurzer Blitz zum Startup
    strip.fill(strip.Color(255, 255, 255));
    strip.show();
    delay(200);
    strip.clear();
    strip.setBrightness(50); // Zurück auf Normalhelligkeit für Status-LEDs
    strip.show();

    audioEngine.updatePirActivity();
    randomSeed(esp_random());
    spi_onboardSD->begin();

    Serial.println("Init SD...");
    if (!SD.begin(SD_CS_PIN, *spi_onboardSD)) {
        ledCtrl.setBootStatusLeds(1, false);
        Serial.println("SD FAIL!"); 
        delay(3000);
        while (true); 
    }
    ledCtrl.setBootStatusLeds(1, true);
    Serial.println("SD OK."); digitalWrite(LED_BUILTIN, HIGH);

    // --- Konfiguration laden ---
    config.load();

    // --- WLAN verbinden (wenn eine der Integrationen aktiviert ist) ---
    if (config.homeassistant_mqtt_enabled || config.friendlamp_mqtt_enabled) {
        mqttHandler.setupWifi();
    }
 

    // --- LED_Ring Setup ---
    if (config.friendlamp_enabled) {
        // updateLength wird ans Ende des Setups verschoben, da es den LED Buffer sofort löscht!
        strip.setBrightness(config.led_brightness); // Set brightness from config
        Serial.println("Friendship Lamp (LED Ring) configured. Brightness: " + String(config.led_brightness));
    }

    Serial.println("Scanning directories...");
    File root = SD.open("/"); if (!root) { Serial.println("ROOT FAIL!"); while (true); }
    audioEngine.findMp3Directories(root);
    root.close();

    audioEngine.init();

    audio.setPinout(I2S_BCLK, I2S_LRCLK, I2S_DOUT);
    
    // Register the new callback system for ESP32-audioI2S v3.0+
    Audio::audio_info_callback = [](Audio::msg_t msg) {
        if (msg.e == Audio::evt_eof) {
            audioEngine.onAudioEof();
        }
    };

    // The initial volume is initialized via audioEngine internally now, 
    // but Audio hardware init is here.
    Serial.println("Audio hardware pins configured");


    // --- Boot Status abwarten und LEDs prüfen ---
    if ((config.homeassistant_mqtt_enabled || config.friendlamp_mqtt_enabled) && WiFi.status() == WL_CONNECTED) {
        mqttHandler.forceReconnect(); // Trigger initial MQTT connect to show LED 1 status
    }
    
    // Lass die Boot-Status LEDs für 2 Sekunden leuchten, um sie zu überprüfen
    delay(2000); 

    // --- LED_Ring finale Einstellung nach Boot Sequence ---
    if (config.friendlamp_enabled && config.led_count > 0 && config.led_count != DEFAULT_LED_COUNT) {
        strip.updateLength(config.led_count);
    }
    
    if (!webManager.apMode) {
        strip.clear(); 
        strip.show();
    } else {
        // Falls updateLength die LEDs gelöscht hat, setzen wir sie für den AP-Modus wieder rot
        ledCtrl.setApModeLed(true);
    }

    Serial.println("Setup complete.");
    mqttHandler.publish(config.getTopicStatus(), "Initialized", true); // Bereit-Status
    Serial.println("Waiting for PIR or button...");
}

// --- Loop --- 
void loop() {
    if (webManager.pendingRestart) {
        if (millis() > webManager.restartTime) {
            ESP.restart();
        }
        return; 
    }
    if (webManager.apMode) {
        webManager.processDns();
        return; 
    }
    
    ledCtrl.update();
    
    mqttHandler.update();
    audioEngine.update();
    
    if (config.friendlamp_enabled) {
        if (ledCtrl.ledActive && millis() > ledCtrl.ledTimeout) {
            ledCtrl.ledActive = false;
            ledCtrl.startFadeOut();
        }
    }

    vTaskDelay(1);
}

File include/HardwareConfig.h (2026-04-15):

#pragma once
#include <Arduino.h>

// --- Central Hardware Pin Definitions ---
// Keeping pins centralized prevents duplicate values and bugs
// when changing hardware connections.

const int POT_PIN = 4;
const int PIR_PIN = 18;
const int BUTTON_PIN = 17; 
const int LED_PIN = 16;
const int SD_CS_PIN = SS;

// Default count, dynamic value is stored in AppConfig.led_count
const int DEFAULT_LED_COUNT = 16;

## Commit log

2026-03-24 docs: Add config.txt template for SD-Card
    [config.txt]
2026-03-24 feat: Add Friendship Lamp functionality via RGB LED Ring
    [config.txt]
2026-03-25 docs: Add wiring diagrams and PDF documentation
2026-03-26 feat: Add dual MQTT broker support for friendship lamp
    [config.txt]
2026-03-27 feat: switch from deep sleep to standby to keep MQTT alive
2026-03-27 fix: resolve vTaskPriorityDisinheritAfterTimeout by calling NeoPixel show() only once on state change
    [main.cpp]
2026-03-27 feat: Update project, fix build error, and add documentation
    [config.txt]
2026-03-27 Update MQTT configuration settings in config.txt
    [config.txt]
2026-03-28 feat: Add LED fade effects and split MQTT integration
    Implements smooth fade-in/out for the LED ring and adds configuration options for brightness and duration.
    Refactors the MQTT integration into two separate flags for Home Assistant and the friendship lamp feature, allowing independent control. Updates README with details on the new configuration.
    [config.txt]
2026-03-31 feat: Implement web configuration portal and MQTT TLS
    This commit introduces two major features:
    - **Web Configuration Portal:** If the device cannot connect to a known Wi--Fi network, it starts its own Access Point (`Zwitscherbox`). This allows for easy configuration of all settings (Wi--Fi, MQTT, etc.) via a web browser without needing to manually edit the `config.txt` on the SD card.
    - **MQTT TLS Encryption:** TLS encryption is now supported for the external "Friendship Lamp" MQTT broker, increasing security.
    Additionally, the serial port detection in `platformio.ini` has been improved, and the necessary libraries for the web server have been added.
    [config.txt]
2026-04-02 feat(led): add complementary color mode and configurable topics
    - Differentiate between ZWITSCHERBOX_TOPIC and FRIENDLAMP_TOPIC in config
    - Introduce fadeRingMode to light every 3rd LED in complementary color for friendlamp msgs
    - Update README.md to describe the new LED behavior and topics
    - Reduce LED_COUNT from 16 to 8
    - Fix ESP.restart() handling after saving the config
    [main.cpp]
2026-04-02 Anwenderdokumentation und Projektdateien hinzugefügt
    [ZwitscherKleinschmal.stl, ZwitscherKleinschmal_Boden.stl, ZwitscherKleinschmal_Deckel.stl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]
2026-04-02 Photos von der Zwitscherbox hinzugefügt
2026-04-03 Textänderungen im HTML Code vorgenommen, um die Webseite zu verbessern. Es wurden auch einige Fehler behoben und die Ladezeit der Seite optimiert. Weitere Informationen zu den Änderungen finden Sie i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
    [main.cpp]
2026-04-04 Photos und PDF von Zwitscher hinzugefügt
2026-04-07 Fix: Ignore '#' prefix in MQTT JSON hex color strings to support Freundschaftslampe payloads
    [main.cpp]
2026-04-07 Enhance: Make NeoPixel LED count configurable via WebUI
2026-04-07 BugFix bei der Payload für die Freundschaftslampe, damit sie auch mit der neuen Version der Lampe funktioniert. Es wurden die Datenstrukturen angepasst und die Payload entsprechend aktualisiert, um d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
    [main.cpp]
2026-04-07 Fix: Heap memory fragmentation causing HTTP Failure on Web UI
    [main.cpp]
2026-04-10 fix: make OTA NeoPixel feedback synchronous
    [main.cpp]
2026-04-14 chore: Security improvement - ignore config.txt to prevent credential leaks
    [config.example.txt]
2026-04-15 refactor: Extracted WebManager and LedController modules for better maintainability
2026-04-15 fix: Turn off blue LED after OTA check finds no updates
    [main.cpp]
2026-04-15 feat: Add visual LED boot status sequence
2026-04-15 fix: Correct LED boot sequence behavior and indices
    [MqttHandler.cpp, main.cpp]
2026-04-15 fix: Persist AP Mode LEDs after boot sequence
    [main.cpp]
2026-04-15 fix: Clear NeoPixel artifacts to prevent single led bug during soft-reboot
    [MqttHandler.cpp, main.cpp]
2026-04-15 refactor: Migrate LedController to OOP Strategy Pattern
2026-04-15 build: Add support for standard ESP32 Dev Module
2026-04-15 build: Revert environment default to v2 (ESP32-S3-AMP)
2026-04-15 fix: Wait to initialize FreeRTOS mutex until setup
    [main.cpp]
2026-04-15 fix: AudioEngine used wrong PIR pin (16 instead of 18)
    [AudioEngine.cpp]
2026-04-15 fix: Removed overrides for yb_esp32s3_amp_v2 pins_arduino.h values
    [main.cpp]
2026-04-15 fix: Use publishLamp for Friendship payload in AudioEngine.cpp
    [AudioEngine.cpp]
2026-04-16 docs: Add Quiet Time and Boot Sequence LED descriptions to README
2026-04-16 Clarify LED ring behavior in README
    Updated the README to clarify the behavior of the LED ring regarding presence detection.
2026-04-16 Update README for MQTT and LED Ring details
    Clarified that real-time status updates via MQTT are sent only to the internal broker and updated the description of the LED Ring color setting.
2026-04-17 Fix OTA failed status reset and remove explicit CA certificate verification
    [MqttHandler.cpp]
2026-04-17 Add responsive OTA LED ring animation
2026-04-17 Fix delayed MQTT boot status LEDs remaining stuck ON
    [MqttHandler.cpp]
2026-04-22 Fix PIR not triggering due to ESP32-audioI2S v3 API breaking changes (audio_eof_mp3 removed)
    [main.cpp]
2026-04-26 bug in mqtt handler
    [AudioEngine.cpp, MqttHandler.cpp]
2026-05-03 über die weboberfläche kann der pir sensor aktiviert und deaktiviert werden.
2026-05-24 feat: display last octet of IP address as blinking LED ring sequence on folder button long press (>3s)
2026-05-24 docs: document long press button IP visualization feature in README
2026-05-26 OTA Update - Fix to manage the OTA update process and ensure that the device can receive updates correctly.
    [MqttHandler.cpp]
2026-07-05 fix: resolve RAINBOW color parsing and status publishing issue by preventing leading # on publish and handling leading # on parse
    [AudioEngine.cpp, MqttHandler.cpp]
